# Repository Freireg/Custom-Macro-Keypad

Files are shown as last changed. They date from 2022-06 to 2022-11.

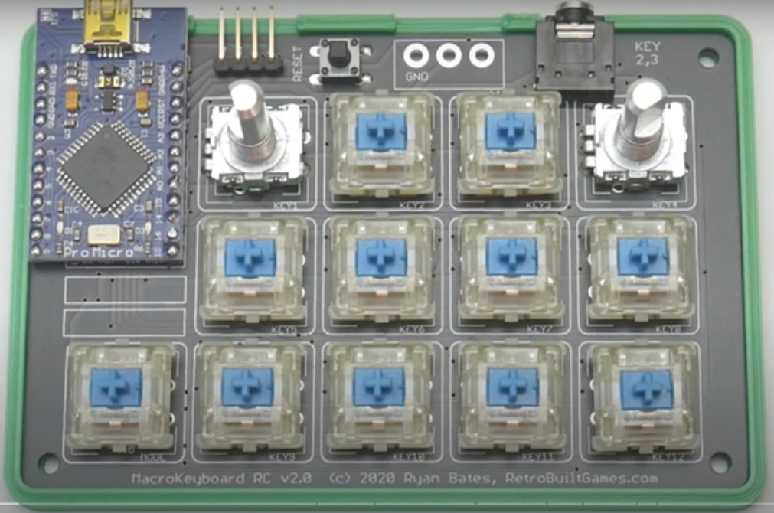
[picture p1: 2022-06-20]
Reference Layout.png

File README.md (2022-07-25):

# Custom-Macro-Keypad
Custom macro mechanical keypad using a ESP32

# Index
- [Overview](#overview)
- [Hardware](#hardware)
- [Firmware](#firmware)
- [Applications](#applications)
# Overview
This projects intends to make a custom keyboard with bluetooth connection using an ESP32 W-ROOM. 
It can have a number of custom configuration and even a Wi-fi setup to work with IoT devices. But, this first implementation will focus on a macro-keyboard setup.
# Hardware
Needed hardware:
> - ESP32 W-ROOM
> - Cherry Mechanical Keys
> - Incremental Enconder (part number: EN12-HN22AF25)
> - RGB LED (part number: 598-8610-307F)
> - Battery charging module / Voltage Regulator (PartNumber: J5019)
> - LiPo Battery (3.7V / 2450mAh)

Schematics and PCB layout can be found in the ["Nano-keyboard" Folder](https://github.com/Freireg/Custom-Macro-Keypad/tree/main/Nano-keyboard)

# Firmware
## Library
## How to read a button matrix
# Applications

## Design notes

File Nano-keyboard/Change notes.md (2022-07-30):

# Self notes
- To review:
  - ESP Pins:
    <!-- - Encoder U6: remove pin A from gpio12 -->
    <!-- - Remove everything from gpio0 to gpio17, if possible -->
    <!-- - Rout tracks for I2C external port -->
  - Add LED transistors (and change to common anode)
- Correct J5019 footprint
<!-- - Add pulldown on function button -->
<!-- - Add decoupling capacitor on the LDO -->
- Add "master switch"
- Add battery connector
- Via sizes

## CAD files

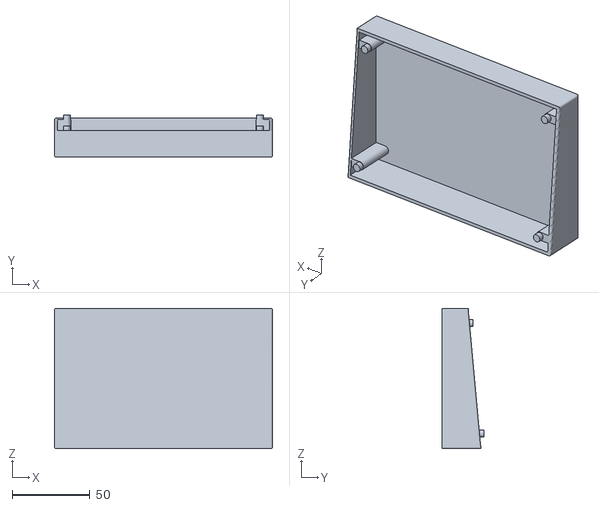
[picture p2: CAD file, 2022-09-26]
Nano-keyboard/Case V3.stl
140.0 x 27.0 x 90.0

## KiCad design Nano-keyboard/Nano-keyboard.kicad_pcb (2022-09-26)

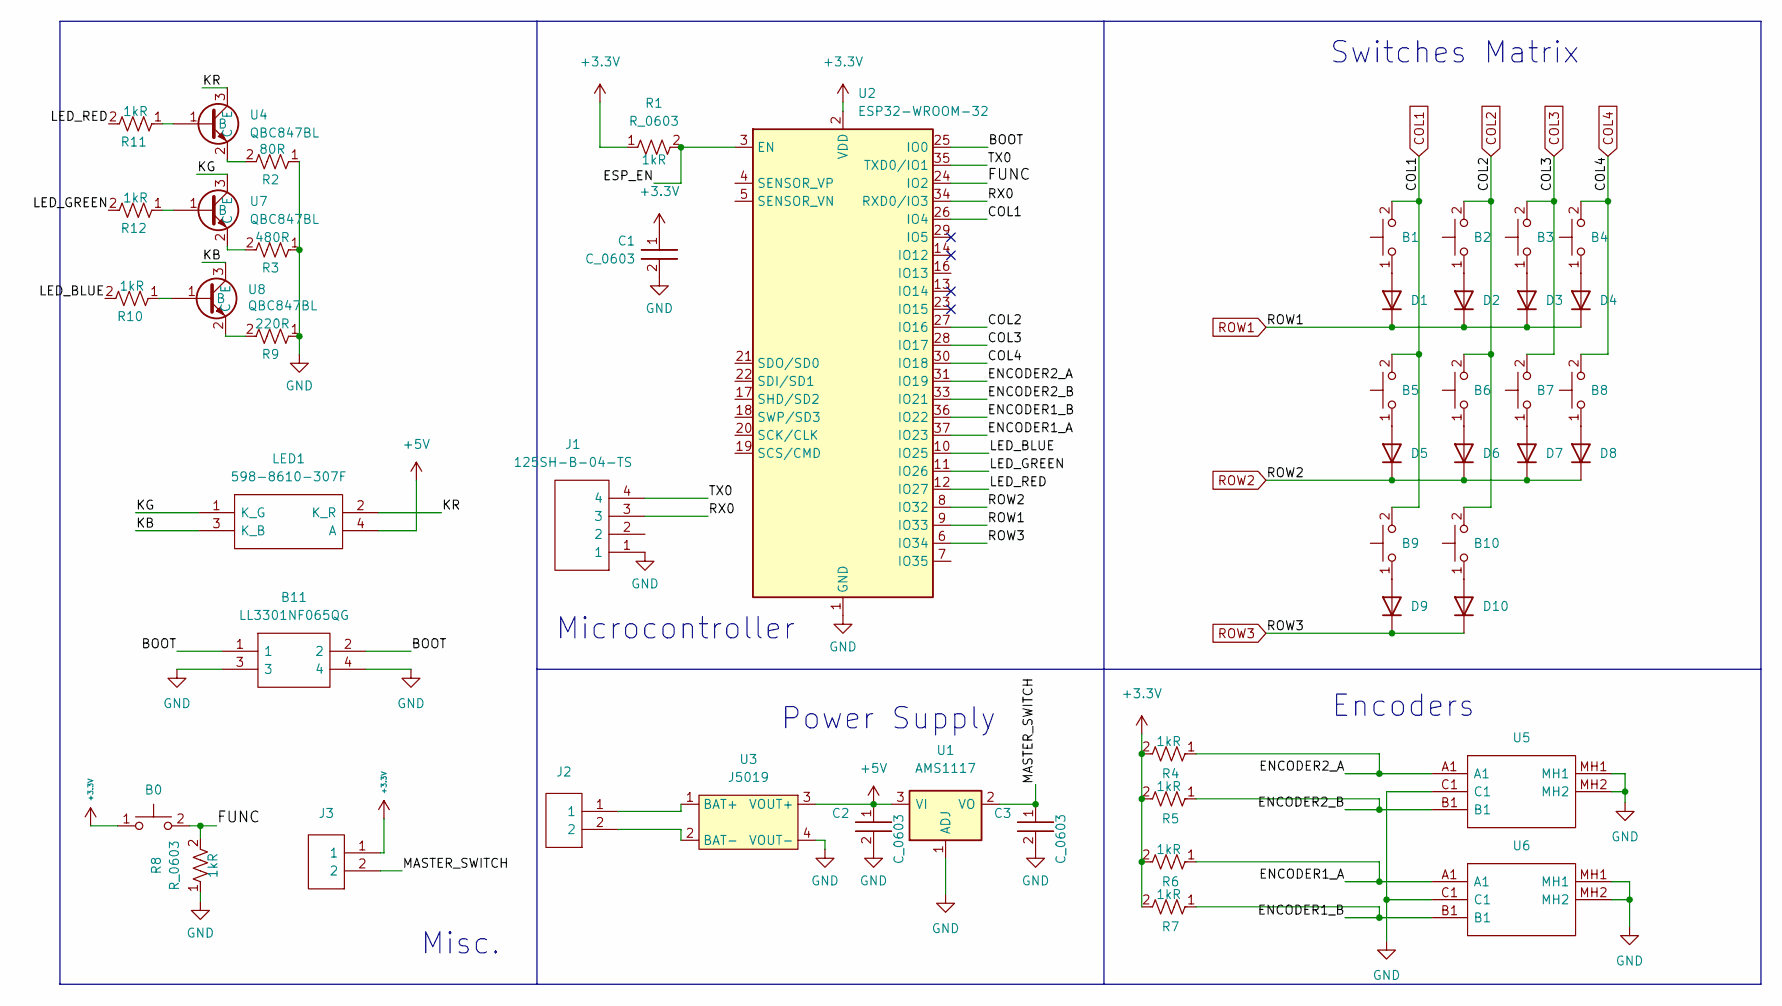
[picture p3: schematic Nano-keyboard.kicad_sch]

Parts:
B0, B1, B2, B3, B4, B5, B6, B7, B8, B9, B10: Cherry_Switch_1U_PCB; SW_Cherry_MX_1.00u_PCB
B11: LL3301NF065QG; Manufacturer_Part_Number LL3301NF065QG; Mouser Part Number 612-LL3301NF065QG
C1, C2, C3: C_0603; C_0603_1608Metric
D1, D2, D3, D4, D5, D6, D7, D8, D9, D10: 1N914; D_DO-35_SOD27_P7.62mm_Horizontal
J1: 125SH-B-04-TS; SHDR4W35P0X125_1X4_800X320X420P; Manufacturer_Part_Number 125SH-B-04-TS
J2, J3: 25SH-B-02-TS; 25SHB02TS; Manufacturer_Part_Number 125SH-B-02-TS
LED1: 598-8610-307F; 5988610307F; Manufacturer_Part_Number 598-8610-307F; Mouser Part Number 645-598-8610-307F
R1, R2, R3, R4, R5, R6, R7, R8, R9, R10, R11, R12: R_0603; R_0603_1608Metric
U1: AMS1117; SOT-223-3_TabPin2
U2: ESP32-WROOM-32
U3: J5019; J5019-module
U4, U7, U8: QBC847BL; SOT96P237X111-3N
U5, U6: EN12-HN22AF25; EN12HN22AF25; Manufacturer_Part_Number EN12-HN22AF25; Mouser Part Number 858-EN12-HN22AF25

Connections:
+3V3: B0.1, C1.1, J3.1, R1.1, R4.2, R5.2, R6.2, R7.2, U2.2 (VDD)
/BOOT: B11.1, B11.2, U2.25 (IO0)
/ENCODER1_A: R6.1, U2.37 (IO23), U6.A1
/ENCODER1_B: R7.1, U2.36 (IO22), U6.B1
/ENCODER2_A: R4.1, U2.31 (IO19), U5.A1
/ENCODER2_B: R5.1, U2.33 (IO21), U5.B1
/ESP_EN: R1.2, U2.3 (EN)
/FUNC: B0.2, R8.2, U2.24 (IO2)
/KB: LED1.3 (K_B), U8.3 (E)
/KG: LED1.1 (K_G), U7.3 (E)
/KR: LED1.2 (K_R), U4.3 (E)
/LED_BLUE: R10.2, U2.10 (IO25)
/LED_GREEN: R12.2, U2.11 (IO26)
/LED_RED: R11.2, U2.12 (IO27)
/MASTER_SWITCH: C3.1, J3.2, U1.2 (VO)
/RX0: J1.3, U2.34 (RXD0/IO3)
/TX0: J1.4, U2.35 (TXD0/IO1)
COL1: B1.2, B5.2, B9.2, U2.26 (IO4)
COL2: B2.2, B6.2, B10.2, U2.27 (IO16)
COL3: B3.2, B7.2, U2.28 (IO17)
COL4: B4.2, B8.2, U2.30 (IO18)
GND: B11.3, B11.4, C1.2, C2.2, C3.2, J1.1, R2.1, R3.1, R8.1, R9.1, U1.1 (ADJ), U2.1 (GND), U2.15 (GND), U2.38 (GND), U2.39 (GND), U3.4 (VOUT-), U5.C1, U5.MH1, U5.MH2, U6.C1, U6.MH1, U6.MH2
unnamed: B1.1, D1.2 (A)
unnamed: B2.1, D2.2 (A)
unnamed: B3.1, D3.2 (A)
unnamed: B4.1, D4.2 (A)
unnamed: B5.1, D5.2 (A)
unnamed: B6.1, D6.2 (A)
unnamed: B7.1, D7.2 (A)
unnamed: B8.1, D8.2 (A)
unnamed: B9.1, D9.2 (A)
unnamed: B10.1, D10.2 (A)
unnamed: J2.1, U3.1 (BAT+)
unnamed: J2.2, U3.2 (BAT-)
unnamed: R2.2, U4.2 (C)
unnamed: R3.2, U7.2 (C)
unnamed: R9.2, U8.2 (C)
unnamed: R10.1, U8.1 (B)
unnamed: R11.1, U4.1 (B)
unnamed: R12.1, U7.1 (B)
ROW1: D1.1 (K), D2.1 (K), D3.1 (K), D4.1 (K), U2.9 (IO33)
ROW2: D5.1 (K), D6.1 (K), D7.1 (K), D8.1 (K), U2.8 (IO32)
ROW3: D9.1 (K), D10.1 (K), U2.6 (IO34)

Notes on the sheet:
Microcontroller
Power Supply
Encoders
Misc.
Switches Matrix

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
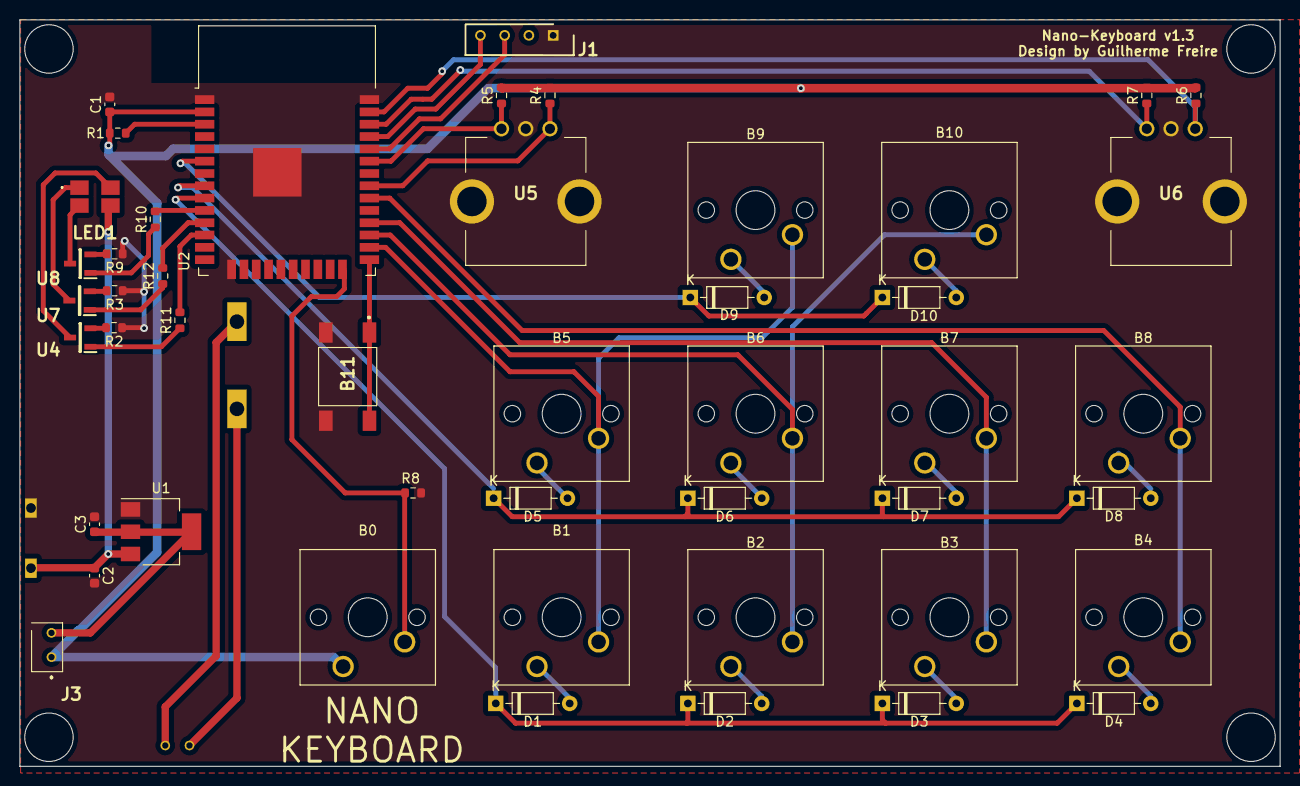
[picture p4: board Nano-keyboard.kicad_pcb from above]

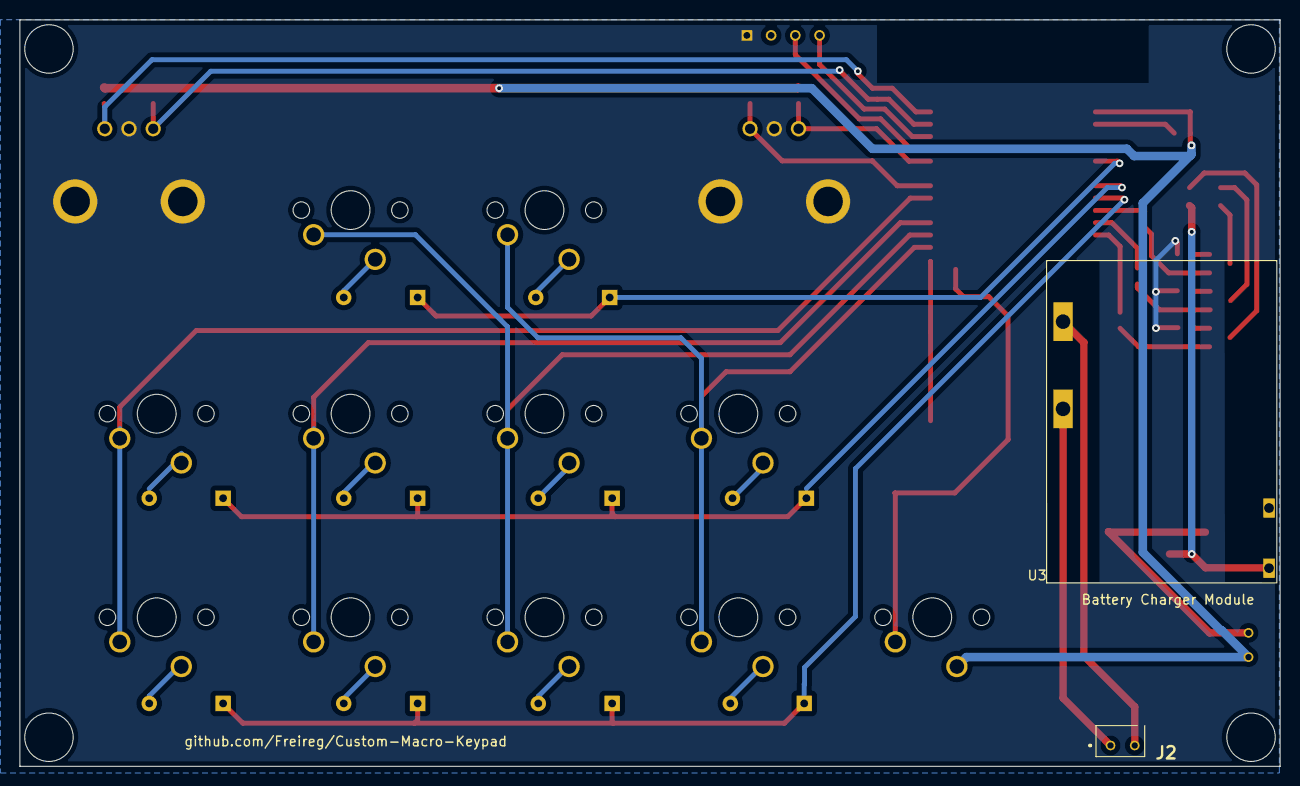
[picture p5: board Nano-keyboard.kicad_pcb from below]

Board: 2 copper layers, 130.0 x 77.0 mm, 49 parts (2 on the bottom side), 44 nets.

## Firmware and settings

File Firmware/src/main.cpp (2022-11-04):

/**
 * This example turns the ESP32 into a Bluetooth LE keyboard that writes the words, presses Enter, presses a media key and then Ctrl+Alt+Delete
 */
#include <NanoKeyboard.hpp>

NanoKeyboard keyboard;

void setup(){
  keyboard.setup();
}

void loop(){
  if(keyboard.begin())
  {
    keyboard.run();
  }
}

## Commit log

2022-06-10 First layout design
    [Nano-keyboard.kicad_pcb]
2022-06-13 ESP initial changes
    [Nano-keyboard.kicad_pcb]
2022-06-13 Minor schematic changes
    [Nano-keyboard.kicad_pcb, Nano-keyboard.kicad_sch]
2022-06-13 3D Switch Models
    [Nano-keyboard.kicad_pcb, Nano-keyboard.kicad_sch]
2022-06-13 Minor changes
    [Nano-keyboard.kicad_pcb, Nano-keyboard.kicad_sch]
2022-06-28 Diode Changes
    [Nano-keyboard.kicad_pcb, Nano-keyboard.kicad_sch]
2022-07-01 Charger Module and keyboard layout changes
    [Nano-keyboard.kicad_pcb, Nano-keyboard.kicad_sch]
2022-07-02 Layout changes
    [Nano-keyboard.kicad_pcb, Nano-keyboard.kicad_sch]
2022-07-05 Initial routing
    [Nano-keyboard.kicad_pcb, Nano-keyboard.kicad_sch]
2022-07-06 Added Resistors and Capacitor
    [Nano-keyboard.kicad_pcb, Nano-keyboard.kicad_sch]
2022-07-07 Routing changes
    [Nano-keyboard.kicad_pcb, Nano-keyboard.kicad_sch]
2022-07-08 Routing Done [Pending Revision]
    [Nano-keyboard.kicad_pcb, Nano-keyboard.kicad_sch]
2022-07-08 Added RGB leds
    [Nano-keyboard.kicad_pcb, Nano-keyboard.kicad_sch]
2022-07-11 Board Dimensions changes
    [Nano-keyboard.kicad_pcb]
2022-07-14 3D model updates
    [Nano-keyboard.kicad_pcb, Nano-keyboard.kicad_sch]
2022-07-15 Footprint adjustmetns
    [Nano-keyboard-B_Cu.gbr, Nano-keyboard-B_Mask.gbr, Nano-keyboard-B_Silkscreen.gbr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]
2022-07-28 Adjusting J5019 footprint
    [Nano-keyboard.kicad_pcb]
2022-07-29 added BJTs
    [Nano-keyboard.kicad_pcb, Nano-keyboard.kicad_sch]
2022-07-30 Routing of version 1.2 almest finished
    [Nano-keyboard.kicad_pcb, Nano-keyboard.kicad_sch]
2022-08-02 Finished Routing
    [Nano-keyboard.kicad_pcb]
2022-08-02 Gerber file update
    [Nano-keyboard-B_Cu.gbr, Nano-keyboard-B_Mask.gbr, Nano-keyboard-B_Silkscreen.gbr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]
2022-08-02 Minor update
    [Nano-keyboard-B_Cu.gbr, Nano-keyboard-B_Silkscreen.gbr, Nano-keyboard-Edge_Cuts.gbr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]
2022-08-03 Encoder default application
2022-08-09 PCB V1.2 test firmware
2022-08-12 RGB Led not working
2022-08-12 Addded more spacing between keys and encoder
    [Nano-keyboard.kicad_pcb, Nano-keyboard.kicad_sch]
2022-08-16 Minor adjustments
    [Nano-keyboard.kicad_pcb, Nano-keyboard.kicad_sch]
2022-08-18 [hardware update]
    [Nano-keyboard.kicad_pcb]
2022-09-26 [Layout] LED 5V Supply
    [Case V3.stl, Nano-keyboard.kicad_pcb, Nano-keyboard.kicad_sch]
2022-11-04 [Firmware] Encoder not properly working
2022-11-08 [Firmware] Encoder working
